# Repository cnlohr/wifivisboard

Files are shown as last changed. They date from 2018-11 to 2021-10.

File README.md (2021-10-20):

# wifivisboard

THIS REPO CONTAINS A REFERENCE IMPLEMENTATION FOR ESP-NOW ON THE ESP8266.  Also, previously "esp-freedom"

A project for a minimal reference swadge implemnetation.  

Specifically, this is being made for use with a sermonette for my youth group, to allow for "seeing" wifi. 
I did the initial design in about 2.5 hours on a flight from the hackaday supercon over twitter. 

https://twitter.com/cnlohr/status/1059287135319154688

I will be assembling the boards soon.

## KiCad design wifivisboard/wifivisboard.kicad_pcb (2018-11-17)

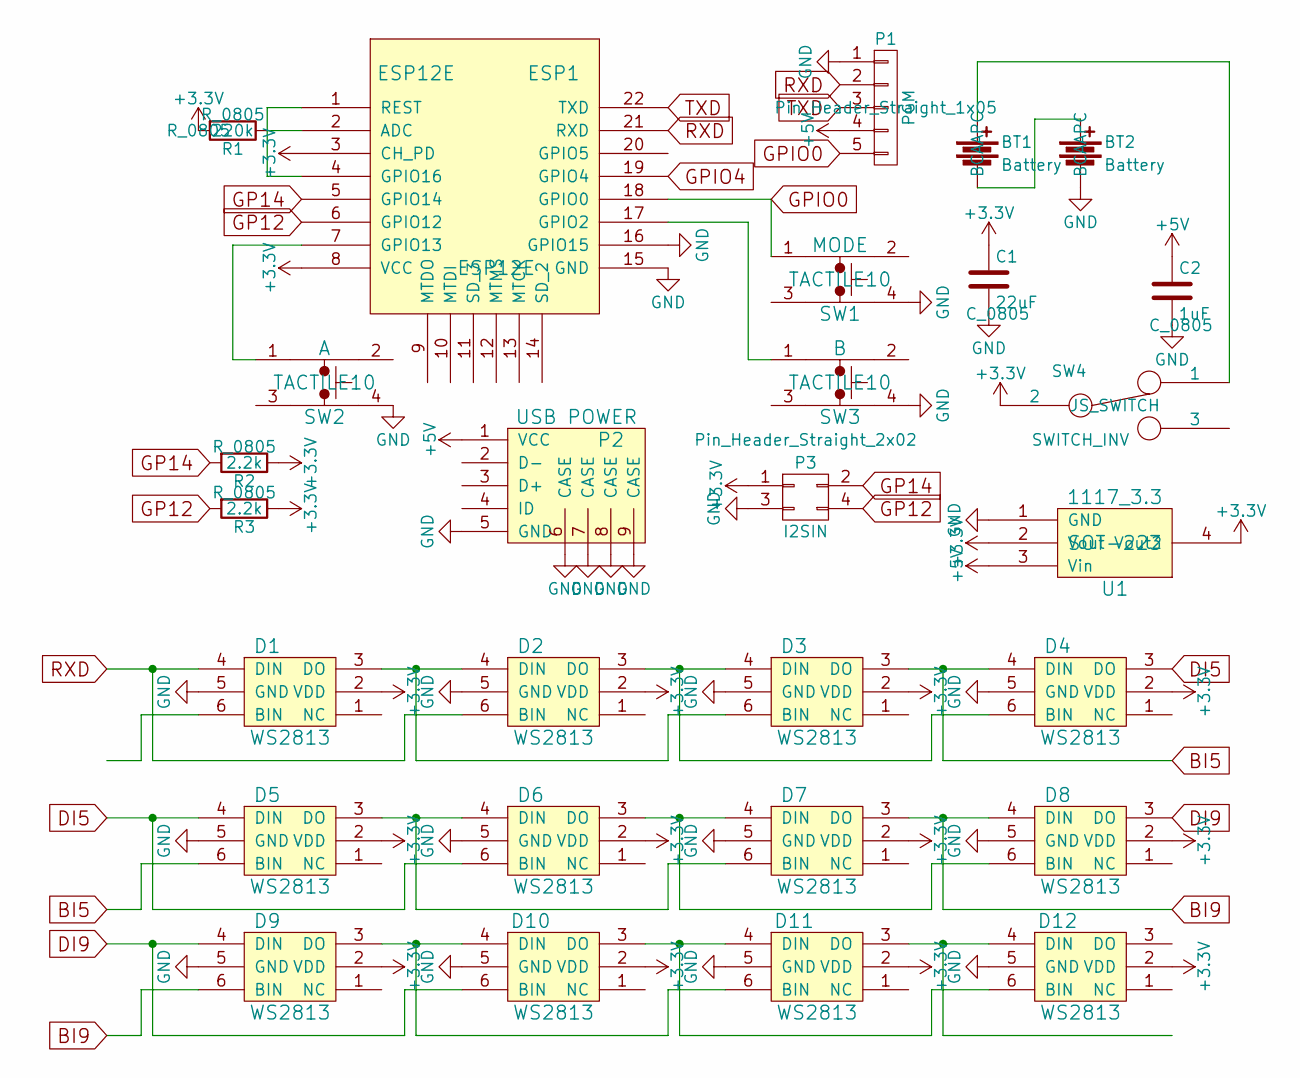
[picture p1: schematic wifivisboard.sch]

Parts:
BT1, BT2: Battery; BCAAPC
C1: 22uF; C_0805
C2: 1uF; C_0805
D1, D2, D3, D4, D5, D6, D7, D8, D9, D10, D11, D12: WS2813
ESP1: ESP12E
P1: PGM; Pin_Header_Straight_1x05
P2: USB POWER; USBMicroB-10118192-0001LF
P3: I2SIN; Pin_Header_Straight_2x02
R1: 220k; R_0805
R2, R3: 2.2k; R_0805
SW1: MODE; TACTILE10
SW2: A; TACTILE10
SW3: B; TACTILE10
SW4: SWITCH_INV; JS_SWITCH
U1: 1117_3.3; SOT-223

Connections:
+3V3: C1.1, D1.2 (VDD), D2.2 (VDD), D3.2 (VDD), D4.2 (VDD), D5.2 (VDD), D6.2 (VDD), D7.2 (VDD), D8.2 (VDD), D9.2 (VDD), D10.2 (VDD), D11.2 (VDD), D12.2 (VDD), ESP1.3 (CH_PD), ESP1.8 (VCC), P3.1, R1.2, R2.1, R3.1, SW4.2, U1.2 (Vout), U1.4 (Vout2)
+5V: C2.1, P1.4, P2.1 (VCC), U1.3 (Vin)
BI5: D3.3 (DO), D4.4 (DIN), D5.6 (BIN)
BI9: D7.3 (DO), D8.4 (DIN), D9.6 (BIN)
DI5: D4.3 (DO), D5.4 (DIN), D6.6 (BIN)
DI9: D8.3 (DO), D9.4 (DIN), D10.6 (BIN)
GND: BT2.2, C1.2, C2.2, D1.5 (GND), D2.5 (GND), D3.5 (GND), D4.5 (GND), D5.5 (GND), D6.5 (GND), D7.5 (GND), D8.5 (GND), D9.5 (GND), D10.5 (GND), D11.5 (GND), D12.5 (GND), ESP1.15 (GND), ESP1.16 (GPIO15), P1.1, P2.5 (GND), P2.6 (CASE), P2.7 (CASE), P2.8 (CASE), P2.9 (CASE), P3.3, SW1.4, SW2.4, SW3.4, U1.1 (GND)
GP12: ESP1.6 (GPIO12), P3.4, R3.2
GP14: ESP1.5 (GPIO14), P3.2, R2.2
GPIO0: ESP1.18 (GPIO0), P1.5, SW1.1
unnamed: BT1.1, SW4.1
unnamed: BT1.2, BT2.1
unnamed: D1.3 (DO), D2.4 (DIN), D3.6 (BIN)
unnamed: D2.3 (DO), D3.4 (DIN), D4.6 (BIN)
unnamed: D5.3 (DO), D6.4 (DIN), D7.6 (BIN)
unnamed: D6.3 (DO), D7.4 (DIN), D8.6 (BIN)
unnamed: D10.3 (DO), D11.4 (DIN), D12.6 (BIN)
unnamed: D9.3 (DO), D10.4 (DIN), D11.6 (BIN)
unnamed: D11.3 (DO), D12.4 (DIN)
unnamed: ESP1.1 (REST), ESP1.4 (GPIO16)
unnamed: ESP1.2 (ADC), R1.1
unnamed: ESP1.7 (GPIO13), SW2.1
unnamed: ESP1.17 (GPIO2), SW3.1
RXD: D1.4 (DIN), D2.6 (BIN), ESP1.21 (RXD), P1.2
TXD: ESP1.22 (TXD), P1.3

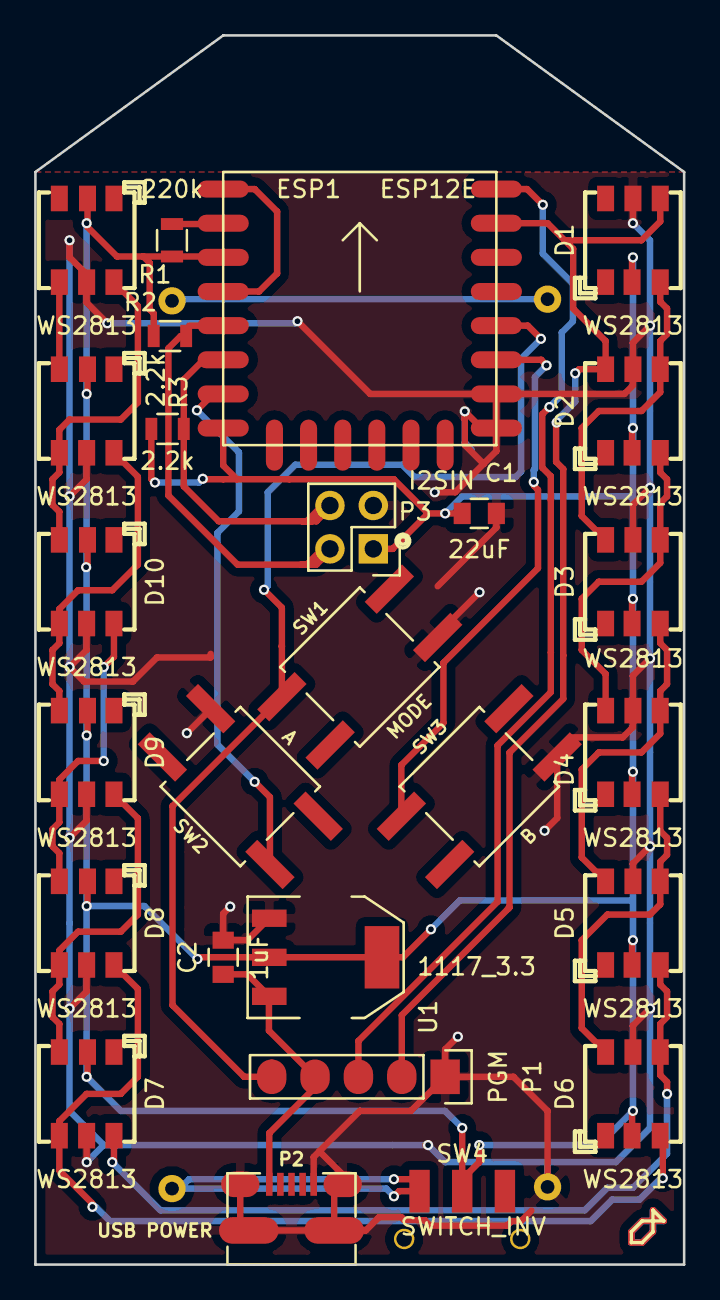
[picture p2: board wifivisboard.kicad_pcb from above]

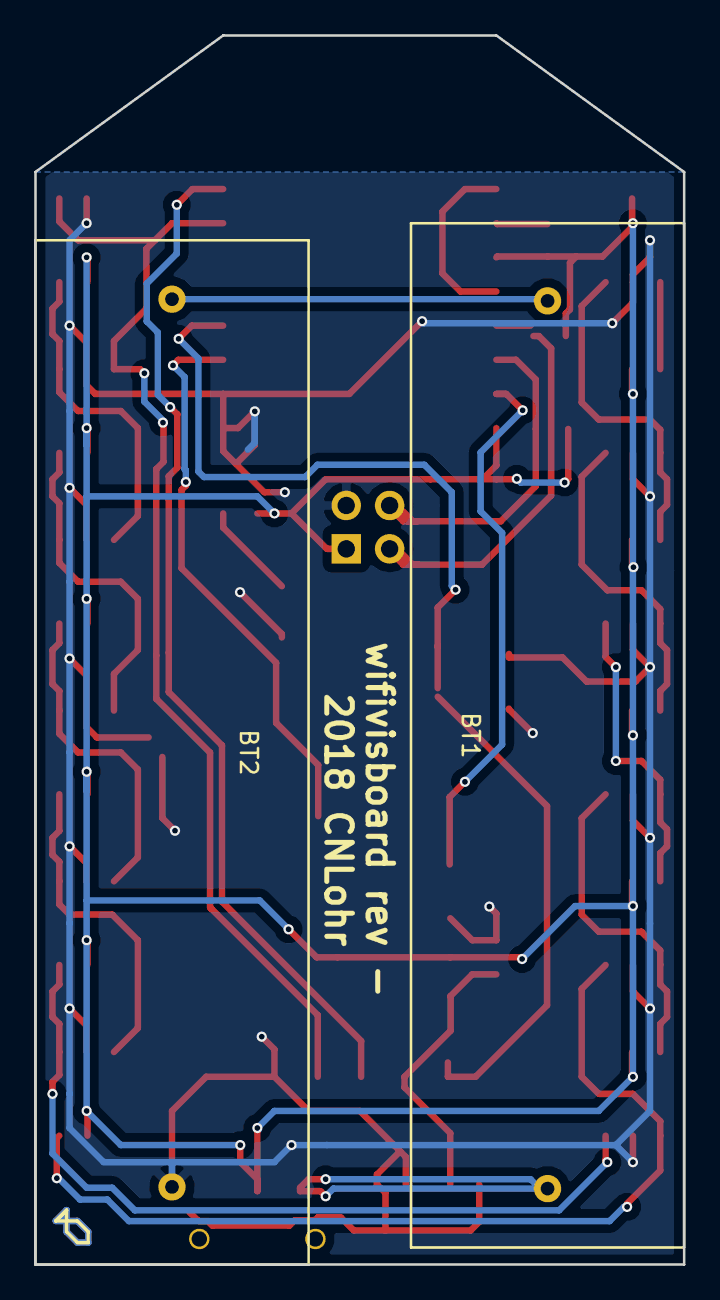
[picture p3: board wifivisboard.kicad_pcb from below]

Board: 2 copper layers, 38.0 x 72.0 mm, 28 parts (2 on the bottom side), 25 nets.

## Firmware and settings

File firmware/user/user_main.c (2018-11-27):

//Copyright 2015, 2018 <>< Charles Lohr, Adam Feinstein see LICENSE file.

/*==============================================================================
 * Includes
 *============================================================================*/

#include "mem.h"
#include "c_types.h"
#include "user_interface.h"
#include "ets_sys.h"
#include "uart.h"
#include "osapi.h"
#include "espconn.h"
#include "esp82xxutil.h"
#include "commonservices.h"
#include "vars.h"
#include <espnow.h>
#include "ws2812_i2s.h"
#include <mdns.h>
#include <string.h>

/*==============================================================================
 * Process Defines
 *============================================================================*/

#define procTaskPrio        0
#define procTaskQueueLen    1
os_event_t    procTaskQueue[procTaskQueueLen];

const int devid = 25;
int DOXMIT = 0;

/*==============================================================================
 * Variables
 *============================================================================*/

static os_timer_t some_timer;
static struct espconn *pUdpServer;
usr_conf_t * UsrCfg = (usr_conf_t*)(SETTINGS.UserData);

/*==============================================================================
 * Functions
 *============================================================================*/

uint32_t EHSVtoHEX( uint8_t hue, uint8_t sat, uint8_t val )
{
	#define SIXTH1 43
	#define SIXTH2 85
	#define SIXTH3 128
	#define SIXTH4 171
	#define SIXTH5 213

	uint16_t or = 0, og = 0, ob = 0;

	hue -= SIXTH1; //Off by 60 degrees.

	//TODO: There are colors that overlap here, consider 
	//tweaking this to make the best use of the colorspace.

	if( hue < SIXTH1 ) //Ok: Yellow->Red.
	{
		or = 255;
		og = 255 - ((uint16_t)hue * 255) / (SIXTH1);
	}
	else if( hue < SIXTH2 ) //Ok: Red->Purple
	{
		or = 255;
		ob = (uint16_t)hue*255 / SIXTH1 - 255;
	}
	else if( hue < SIXTH3 )  //Ok: Purple->Blue
	{
		ob = 255;
		or = ((SIXTH3-hue) * 255) / (SIXTH1);
	}
	else if( hue < SIXTH4 ) //Ok: Blue->Cyan
	{
		ob = 255;
		og = (hue - SIXTH3)*255 / SIXTH1;
	}
	else if( hue < SIXTH5 ) //Ok: Cyan->Green.
	{
		og = 255;
		ob = ((SIXTH5-hue)*255) / SIXTH1;
	}
	else //Green->Yellow
	{
		og = 255;
		or = (hue - SIXTH5) * 255 / SIXTH1;
	}

	uint16_t rv = val;
	if( rv > 128 ) rv++;
	uint16_t rs = sat;
	if( rs > 128 ) rs++;

	//or, og, ob range from 0...255 now.
	//Need to apply saturation and value.

	or = (or * val)>>8;
	og = (og * val)>>8;
	ob = (ob * val)>>8;

	//OR..OB == 0..65025
	or = or * rs + 255 * (256-rs);
	og = og * rs + 255 * (256-rs);
	ob = ob * rs + 255 * (256-rs);
//printf( "__%d %d %d =-> %d\n", or, og, ob, rs );

	or >>= 8;
	og >>= 8;
	ob >>= 8;

	return or | (og<<8) | ((uint32_t)ob<<16);
}


/**
 * This task is called constantly. The ESP can't handle infinite loops in tasks,
 * so this task will post to itself when finished, in essence looping forever
 *
 * @param events unused
 */
static void ICACHE_FLASH_ATTR procTask(os_event_t *events)
{
	CSTick( 0 );

	// Post the task in order to have it called again
	system_os_post(procTaskPrio, 0, 0 );
}

struct cnespsend
{
	uint32_t code;
	uint32_t op;
	uint32_t param1;
	uint32_t param2;
	uint8_t payload[12*3];
}  __attribute__ ((aligned (1))) __attribute__((packed));

/**
 * This is a timer set up in user_main() which is called every 100ms, forever
 * @param arg unused
 */
static void ICACHE_FLASH_ATTR timer100ms(void *arg)
{
	static int k;
	k+=2;
	if( k > 150 ) k = 0;
	struct cnespsend thisesp;

	memset( &thisesp, 0, sizeof(thisesp) );
	thisesp.code = 0xbeefbeef;
	thisesp.op = 3;
	thisesp.param1 = 66;
	thisesp.param2 = 900;
	thisesp.payload[0] = k;  //override
	thisesp.payload[1] = 160;
	thisesp.payload[2] = 0;
	thisesp.payload[3] = 175;
	thisesp.payload[4] = 100;

			//P1 is the offset
			//P2 is the multiplier
			//payload[0] = is the override if op is 4
			//payload[1] = max hue
			//payload[2] = flip hue (if true)
			//payload[3] = hue offset
			//payload[4] = bright mux

/*	int i;
	for( i = 0; i < 12; i++ )
	{
		uint32_t color = EHSVtoHEX( i*20, 255, 255 );
		thisesp.payload[i*3+0] = color>>8;
		thisesp.payload[i*3+1] = color;
		thisesp.payload[i*3+2] = color>>16;
	}*/

	if( DOXMIT )
		espNowSend( &thisesp, sizeof(thisesp) );
	CSTick( 1 ); // Send a one to uart
}

/**
 * UART RX handler, called by the uart task. Currently does nothing
 *
 * @param c The char received on the UART
 */
void ICACHE_FLASH_ATTR charrx( uint8_t c )
{
	//Called from UART.
}

/**
 * This is called on boot for versions ESP8266_NONOS_SDK_v1.5.2 to
 * ESP8266_NONOS_SDK_v2.2.1. system_phy_set_rfoption() may be called here
 */
void user_rf_pre_init(void)
{
	; // nothing
}

/**
 * Required function as of ESP8266_NONOS_SDK_v3.0.0. Must call
 * system_partition_table_regist(). This tries to register a few different
 * partition maps. The ESP should be happy with one of them.
 */
void ICACHE_FLASH_ATTR user_pre_init(void)
{
	LoadDefaultPartitionMap();
}




uint8_t lbuf[12*3];

/**
 * This callback function is called whenever an ESP-NOW packet is received
 *
 * @param mac_addr The MAC address of the sender
 * @param data     The data which was received
 * @param len      The length of the data which was received
 */
void ICACHE_FLASH_ATTR espNowRecvCb(uint8_t* mac_addr, uint8_t* data, uint8_t len)
{
    // Buried in a header, goes from 1 (far away) to 91 (practically touching)
    uint8_t rssi = data[-51];
	static uint8_t lastrssi;
	uint8_t totalrssi = rssi + lastrssi;
	lastrssi = rssi;

	struct cnespsend * d = (struct cnespsend*)data;


	if( d->code != 0xbeefbeef ) return;
	switch( d->op )
	{
	case 0:
		//printf( "Pushing %p %p\n", d->payload, data );
		ws2812_push( d->payload, 12*3 );
		break;
	case 1:
		ws2812_push( d->payload + 12*3*devid, 12*3 );
		break;
	case 2:
		if( d->param1 == devid )
			ws2812_push( d->payload, 12*3 );
		break;
	case 3:
	case 4:
		{
			int r = (d->op==3)?totalrssi:d->payload[0];
			int p1 = d->param1;
			int p2 = d->param2;


			if( p2 == 0 ) { printf( "NO P2\n" ); return; }
			int m = ((r - p1) * p2)>>8;

			int hue = m;
			if( hue < 0 ) hue = 0;
			if( hue > d->payload[1] ) hue = d->payload[1];
			if( d->payload[2] )
			{
				hue = d->payload[1] - 1 - hue;
			}
			hue += d->payload[3];

			int sat = ( 64 + d->payload[1] - m ) * 4;
			if( sat < 0 ) sat = 0;
			if( sat > 255 ) sat = 255;

			int val = (m + 64) * 4;
			if( val < 10 ) val = 10;
			if( val > 255 ) val = 255;
			uint32_t color = EHSVtoHEX( hue, sat, val );
			int i;
			for( i = 0; i < 12; i++ )
			{
				lbuf[i*3+0] = (((color>>8)&0xff) * d->payload[4])>>8;
				lbuf[i*3+1] = (((color)&0xff) * d->payload[4])>>8;
				lbuf[i*3+2] = (((color>>16)&0xff) * d->payload[4])>>8;
			}
			ws2812_push( lbuf, 12*3 );
		}
		break;
	}

#if 0
    // Debug print the received payload
    char dbg[256] = {0};
    char tmp[8] = {0};
    int i;
    for (i = 0; i < len; i++)
    {
        ets_sprintf(tmp, "%02X ", data[i]);
        strcat(dbg, tmp);
    }
    os_printf("%s, MAC [%02X:%02X:%02X:%02X:%02X:%02X], RSSI [%d], Bytes []\r\n",
              __func__,
              mac_addr[0],
              mac_addr[1],
              mac_addr[2],
              mac_addr[3],
              mac_addr[4],
              mac_addr[5],
              rssi );
#endif


}

/**
 * This is a wrapper for esp_now_send. It also sets the wifi power with
 * wifi_set_user_fixed_rate()
 *
 * @param data The data to broadcast using ESP NOW
 * @param len  The length of the data to broadcast
 */
void ICACHE_FLASH_ATTR espNowSend(const uint8_t* data, uint8_t len)
{
	/// This is the MAC address to transmit to for broadcasting
	static const uint8_t espNowBroadcastMac[] = {0xFF, 0xFF, 0xFF, 0xFF, 0xFF, 0xFF};

    // Call this before each transmission to set the wifi speed
    wifi_set_user_fixed_rate(FIXED_RATE_MASK_ALL, 3); //3 = 11mbit/s B

    // Send a packet
   	esp_now_send((uint8_t*)espNowBroadcastMac, (uint8_t*)data, len);
}

/**
 * This callback function is registered to be called after an ESP NOW
 * transmission occurs. It notifies the program if the transmission
 * was successful or not. It gives no information about if the transmission
 * was received
 *
 * @param mac_addr The MAC address which was transmitted to
 * @param status   MT_TX_STATUS_OK or MT_TX_STATUS_FAILED
 */
void ICACHE_FLASH_ATTR espNowSendCb(uint8_t* mac_addr, uint8_t status)
{
    // os_printf("SEND MAC %02X:%02X:%02X:%02X:%02X:%02X\r\n",
    //           mac_addr[0],
    //           mac_addr[1],
    //           mac_addr[2],
    //           mac_addr[3],
    //           mac_addr[4],
    //           mac_addr[5]);

    switch(status)
    {
        case 0:
        {
            // os_printf("ESP NOW MT_TX_STATUS_OK\r\n");
            break;
        }
        default:
        {
            os_printf("ESP NOW MT_TX_STATUS_FAILED\r\n");
            break;
        }
    }
}

/**
 * Initialize ESP-NOW and attach callback functions
 */
void ICACHE_FLASH_ATTR espNowInit(void)
{
    if(0 == esp_now_init())
    {
        os_printf("ESP NOW init!\r\n");
        if(0 == esp_now_set_self_role(ESP_NOW_ROLE_COMBO))
        {
            os_printf("set as combo\r\n");
        }
        else
        {
            os_printf("esp now mode set fail\r\n");
        }

        if(0 == esp_now_register_recv_cb(espNowRecvCb))
        {
            os_printf("recvCb registered\r\n");
        }
        else
        {
            os_printf("recvCb NOT registered\r\n");
        }

        if(0 == esp_now_register_send_cb(espNowSendCb))
        {
            os_printf("sendCb registered\r\n");
        }
        else
        {
            os_printf("sendCb NOT registered\r\n");
        }
    }
    else
    {
        os_printf("esp now fail\r\n");
    }
}

/**
 * The default method, equivalent to main() in other environments. Handles all
 * initialization
 */
void ICACHE_FLASH_ATTR user_init(void)
{
	// Initialize the UART
	uart_init(BIT_RATE_115200, BIT_RATE_115200);

	os_printf("\r\nesp82XX Web-GUI\r\n%s\b", VERSSTR);

	//Uncomment this to force a system restore.
	//	system_restore();

	// Load settings and pre-initialize common services
	CSSettingsLoad( 0 );
	CSPreInit();

	MakePinGPIO( 0 );
	MakePinGPIO( 2 );
	MakePinGPIO( 13 );
	PIN_DIR_INPUT = (1<<2) | (1<<0) | (1<<13);
	PIN_PULLUP_EN( PERIPHS_IO_MUX_MTCK_U ); //GPIO13

	ws2812_init();

	// Initialize common settings
	CSInit( 0 );

	// Start MDNS services
	SetServiceName( "espcom" );
	AddMDNSName(    "esp82xx" );
	AddMDNSName(    "espcom" );
	AddMDNSService( "_http._tcp",    "An ESP82XX Webserver", WEB_PORT );
	AddMDNSService( "_espcom._udp",  "ESP82XX Comunication", COM_PORT );
	AddMDNSService( "_esp82xx._udp", "ESP82XX Backend",      BACKEND_PORT );

/*
	struct softap_config {
		uint8 ssid[32];
		uint8 password[64];
		uint8 ssid_len;	// Note: Recommend to set it according to your ssid
		uint8 channel;	// Note: support 1 ~ 13
		AUTH_MODE authmode;	// Note: Don't support AUTH_WEP in softAP mode.
		uint8 ssid_hidden;	// Note: default 0
		uint8 max_connection;	// Note: default 4, max 4
		uint16 beacon_interval;	// Note: support 100 ~ 60000 ms, default 100
	} sap;*/
	struct softap_config sap;
	memset( &sap, 0, sizeof( sap ) );
	sap.ssid_len = 0;
	sap.channel = 1;
	sap.authmode = 0;
	sap.ssid_hidden = 1;
	sap.beacon_interval = 60000;

	wifi_softap_set_config(&sap);

	wifi_set_opmode( 2 );
	wifi_set_channel( 1 );

	// Set timer100ms to be called every 100ms
	os_timer_disarm(&some_timer);
	os_timer_setfn(&some_timer, (os_timer_func_t *)timer100ms, NULL);
	os_timer_arm(&some_timer, 20, 1);

	os_printf( "Boot Ok.\n" );

	if( !(PIN_IN & (1<<13)) )
	{
		DOXMIT = 1;
	}

	espNowInit();

	// Add a process and start it
	system_os_task(procTask, procTaskPrio, procTaskQueue, procTaskQueueLen);
	system_os_post(procTaskPrio, 0, 0 );
}

/**
 * This will be called to disable any interrupts should the firmware enter a
 * section with critical timing. There is no code in this project that will
 * cause reboots if interrupts are disabled.
 */
void ICACHE_FLASH_ATTR EnterCritical(void)
{
	;
}

/**
 * This will be called to enable any interrupts after the firmware exits a
 * section with critical timing.
 */
void ICACHE_FLASH_ATTR ExitCritical(void)
{
	;
}

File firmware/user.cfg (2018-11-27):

###############################################################################
# User Options
###############################################################################

CHIP  = 8266
IP    = 192.168.4.1     # does not actually set the IP in firmware
PORT  = /dev/ttyUSB0    # could also be /dev/ttyACM0
WEB_PORT     = 80
COM_PORT     = 7777
BACKEND_PORT = 7878
MFS_PAGE_OFFSET  = 532480

ESP_DEFAULT  = $(HOME)/esp8266/esp-open-sdk
ESP_GCC_VERS = 4.8.5

FWBURNFLAGS  = -b 1500000  #uncomment if your programmer supports higher speeds.

OPTS += -DICACHE_FLASH
OPTS += -DUSE_OPTIMIZE_PRINTF
OPTS += -DQUIET_REFLASH  			#Saves about 96 bytes of iram.
OPTS += -DDISABLE_CHARRX 			#Saves about 300 bytes of iram.
#OPTS += -DVERIFY_FLASH_WRITE
#OPTS += -DDEBUG
#OPTS += -DNET_MAXTRIES=10
#OPTS += -DNET_TIMEOUT=3.0
OPTS += -DDISABLE_NET_REFLASH      #Saves about 196 bytes of iram.
OPTS += -DMFS_PAGE_OFFSET=$(MFS_PAGE_OFFSET)
OPTS += -DWS2812_FOUR_SAMPLE
OPTS += -DSOFTAP_CHANNEL=1

#If you need an extra 3kB of flash, you can force esp82xx to use the ROM
#symbols for some internal libgcc functions.
#STRIPPED_LIBGCC=YES

SRCS += user/ws2812_i2s.c

PAGE_TITLE = esp82xx-basic
PAGE_SCRIPTS = $(wildcard page/*.js) # include all javascrpts in ./web/page/
PAGE_HEADING = Welcome to the basic Web-GUI
PAGE_INFO = This is the basic web interface for esp82xx-series chips

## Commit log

2018-11-05 Add design
    [wifivisboard-B.Cu.gbl, wifivisboard-B.Mask.gbs, wifivisboard-B.SilkS.gbo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]
2018-11-17 update design
    [wifivisboard.kicad_pcb]
2018-11-18 update vis board slave object
2018-11-18 add basics
    [user.cfg]
2018-11-18 bump submodule
    [user.cfg]
2018-11-18 add vis board
2018-11-19 add led tools
    [user.cfg]
2018-11-27 update to allow users to become the central node.
    [user.cfg]
